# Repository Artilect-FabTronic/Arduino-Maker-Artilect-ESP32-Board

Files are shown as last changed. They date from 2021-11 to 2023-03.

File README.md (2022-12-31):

# Arduino-Maker-Artilect-ESP32-Board

Conception d'une carte électronique permettant d'accueillir le module **ESP32-WROOM-32D** pour les ateliers Arduino ESP32 :

<!--
![Arduino-Maker-Artilect](/Images/Arduino-Maker-Artilect-Web.png)
-->
<html>
<table align='left' border='0' cellpadding='0'>
<tr class="noBorder">
<td>
<div style="margin: 0 auto; text-align: center">
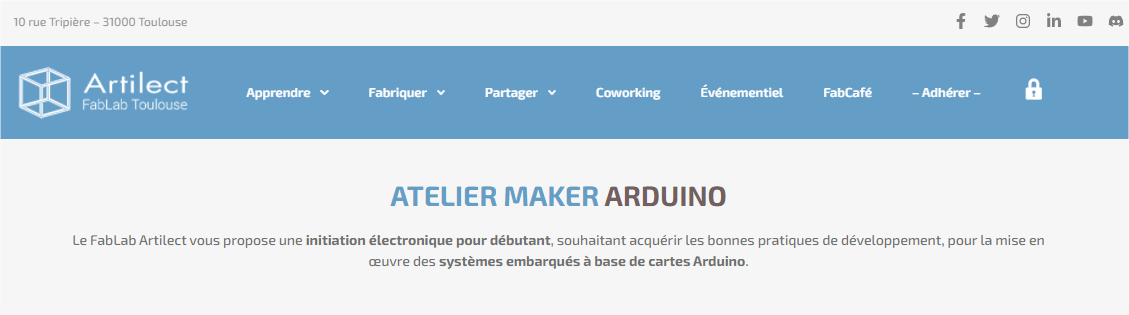
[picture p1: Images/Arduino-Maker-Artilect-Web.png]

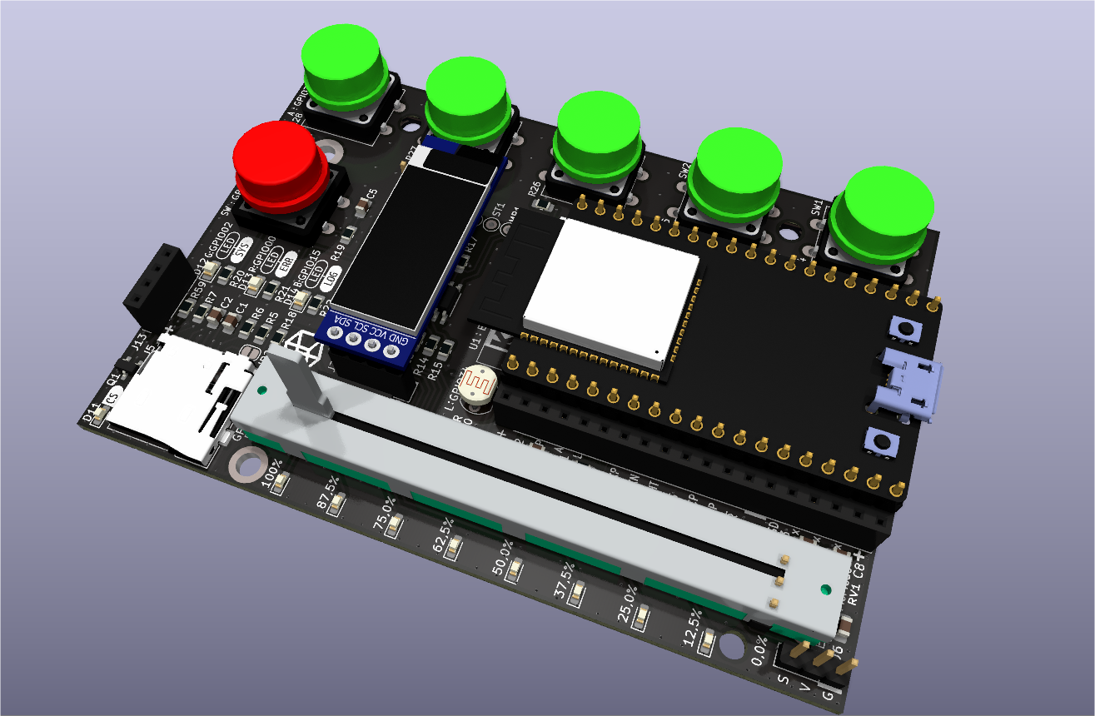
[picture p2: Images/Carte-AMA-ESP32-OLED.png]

</div>
</td>
</tr>
<tr class="noBorder">
<td>
<b>*** Objectifs ***</b><br />
Initiation à l'électronique pour débutant, souhaitant acquérir les bonnes pratiques de développement, pour la mise en œuvre des systèmes embarqués à base de cartes Arduino type ESP32 :<br /><br />
<ul>
  <li>Découvrir la programmation des cartes Arduino en langage C/C++ à travers des cas pratiques.</li>
  <li>Précautions de mise en œuvre, sécurité d’utilisation, alimentation de la carte et des périphériques.</li>
  <li>Prise en main des cartes microcontrôleurs ESP32.</li>
  <li>Mise en œuvre de nombreux périphériques d’entrée/sortie.</li>
  <li>Mise en oeuvre ESP32 avec PlatformIO.</li>
  <li>Vers les bases d’Arduino et au-delà...</li>
</ul>
</td>
</tr>
<tr class="noBorder">
<td>
<div style="margin: 0 auto; text-align: center">
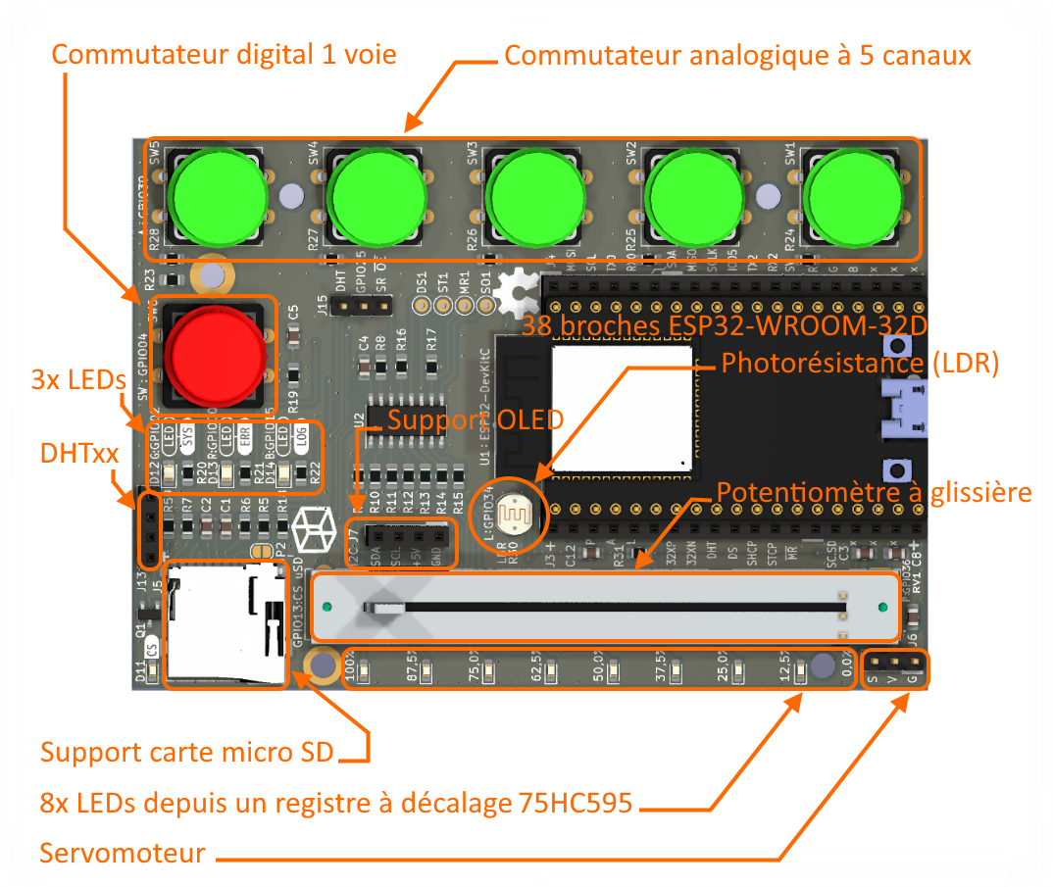
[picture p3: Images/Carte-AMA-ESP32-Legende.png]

</div>
</td>
</tr>
</table>
</p>
<hr>
<br />
</html>

[FabTronic](https://artilect.fr/fabtronic/), la section thématique des makers autour de l’électronique.

<html>
<p>
<table align='left' border='0' cellpadding='0'>
<tr class="noBorder">
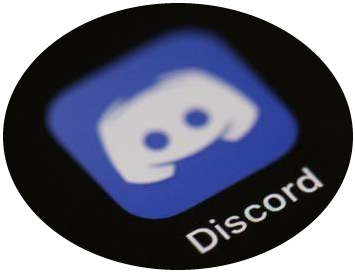
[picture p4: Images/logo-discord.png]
<td></td>
<td>Pour plus d'informations, venez nous rendre visite sur notre chaîne Discord à l'adresse : <a href="https://discord.gg/aPnZ5Q7w6Q">https://discord.gg/aPnZ5Q7w6Q</a><br />
Une fois connecté au serveur FabTronic, nous vous invitons à vous présenter dans le salon <b><i>#présentation</i></b>
</td>
</tr>
</table>
</p>
<hr>
<br />
</html>

---

## [Documentation](Docs/README.md)

### Logiciel utilisé pour la conception de la carte électronique

[KiCad EDA - Logiciel open source de capture schématique et de conception de circuits imprimés](https://kicad.org/)

Téléchargement [Windows All Stable Releases > kicad-6.0.10-x86_64.exe](https://downloads.kicad.org/kicad/windows/explore/stable)

[Logiciel open source](https://fr.wikipedia.org/wiki/Open_source) [EDA](https://fr.wikipedia.org/wiki/Conception_assist%C3%A9e_par_ordinateur_pour_l%27%C3%A9lectronique) / [CAO électronique](https://en.wikipedia.org/wiki/Comparison_of_EDA_software) pour Windows, macOS et Linux.

[Retrouvez la schématique de la carte, ainsi que la liste de matériels nécessaire pour l'assemblage (BOM).](Docs/README.md)

---

## Open Source Hardware Association

<!-- ![oshw-logo](oshw-logo-200-px.png) -->

<html>
<div style="margin: 0 auto; text-align: left">
<table align='left' border='0' cellpadding='0'>
<tr class="noBorder">
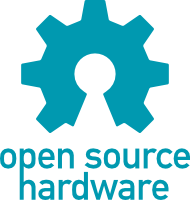
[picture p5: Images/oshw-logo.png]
<td align='center' border='0'></td>
<tr class="noBorder">
<td align='center' border='0'><a href="https://www.oshwa.org/" title="" target="_blank">Source : https://www.oshwa.org/</a></td>
</tr>
</table>
</div>
</html>

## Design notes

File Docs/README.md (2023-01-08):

# Documentation technique du projet

<html>
<div style="margin: 0 auto; text-align: center">
<table align='center' border='0' cellpadding='0'>
<tr class="noBorder">
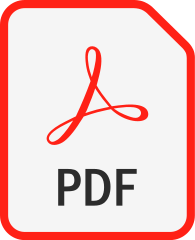
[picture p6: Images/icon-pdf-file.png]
<td></td>
<td><a href="CAO-KiCad-AMA-ESP32-Board.pdf" title="Document PDF de la schématique" target="_blank">Schématique de la carte "<I>A-M-A-ESP32-Board</I>"</a></td>
</tr>
</table>
</div>
</html>

---

## La carte A-M-A-ESP32-Board

| Placement des composants sur une face | Sérigraphie coté cuivre |
| :---: | :---: |
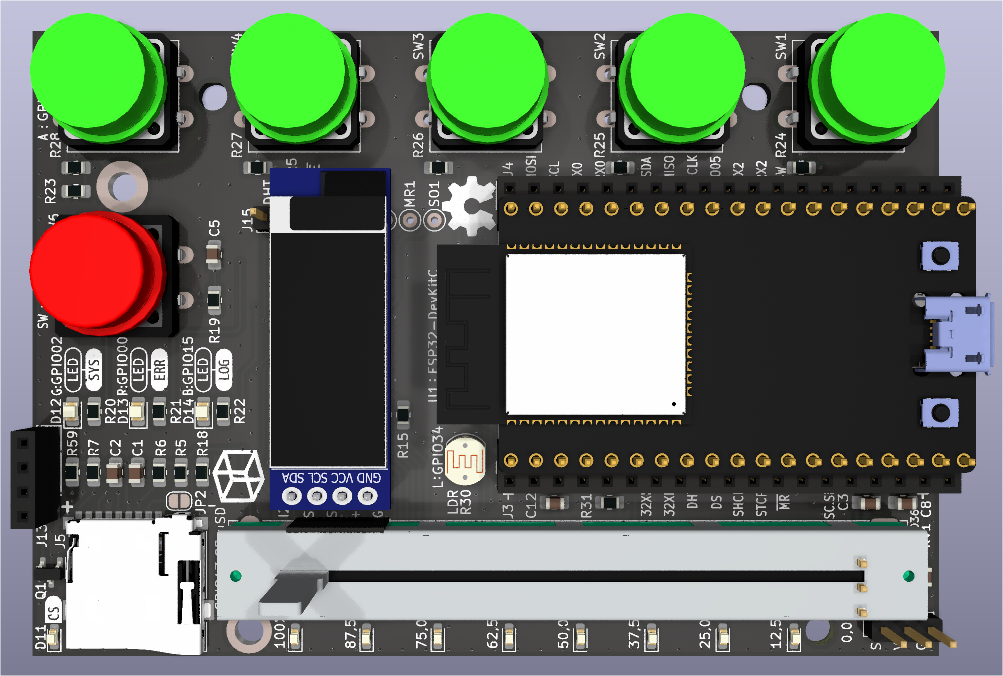
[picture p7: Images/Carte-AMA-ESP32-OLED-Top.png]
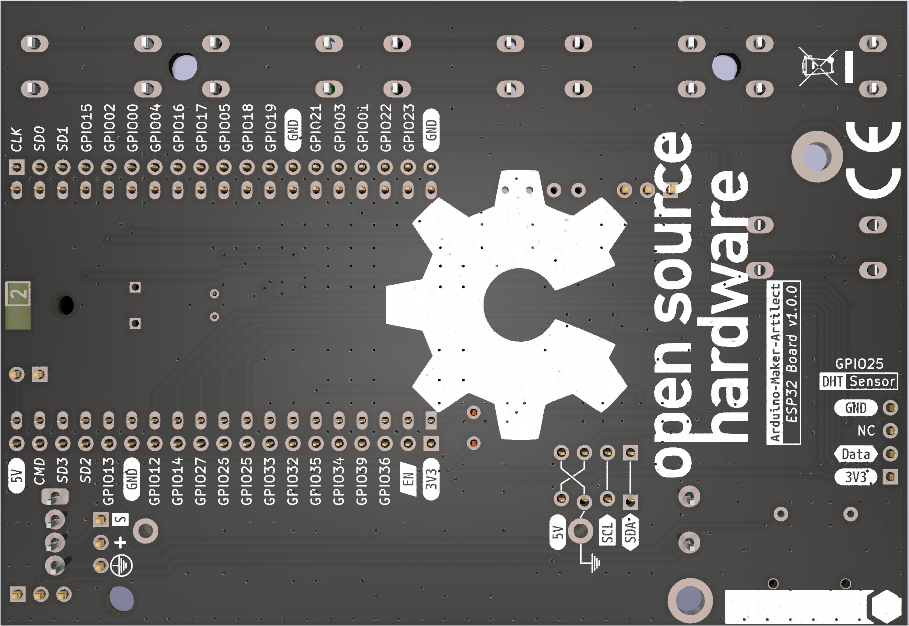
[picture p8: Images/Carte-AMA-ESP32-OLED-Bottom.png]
|  |  |
| Vue de dessus | Vue de dessous |

Voir la liste des composants et le coût de la carte : [Bill Of Materials (BOM)](BOM.md)

Datasheet [ESP32-DevKitC-1](https://docs.espressif.com/projects/arduino-esp32/en/latest/boards/ESP32-DevKitC-1.html)

<!--
<a href="https://fr.aliexpress.com/item/32864722159.html" title="ESP32-WROOM-32D, 38 pin" target="_blank"><img src="../Images/ESP32-WROOM-32D.png" width="480" border="0"></a>
-->

---

Montage de la carte :

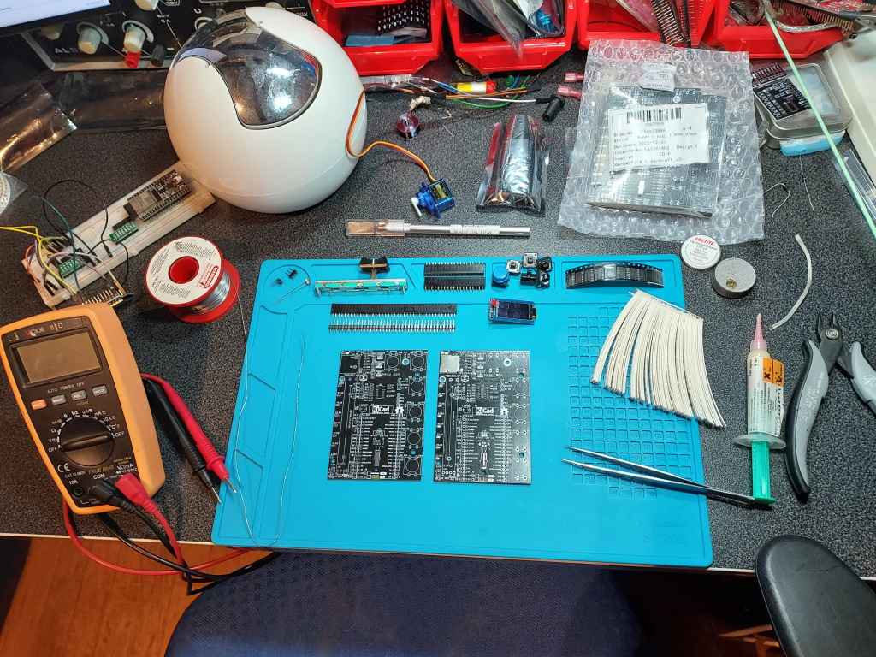
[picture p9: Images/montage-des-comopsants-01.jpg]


---

## Brochage de la carte ESP32-WROOM-32D, 38 broches

<!-- Voir aussi https://www.studiopieters.nl/esp32-pinout/ -->

<html>
<div style="margin: 0 auto; text-align: center">
<table align='center' border='0' cellpadding='0'>
<tr class="noBorder">
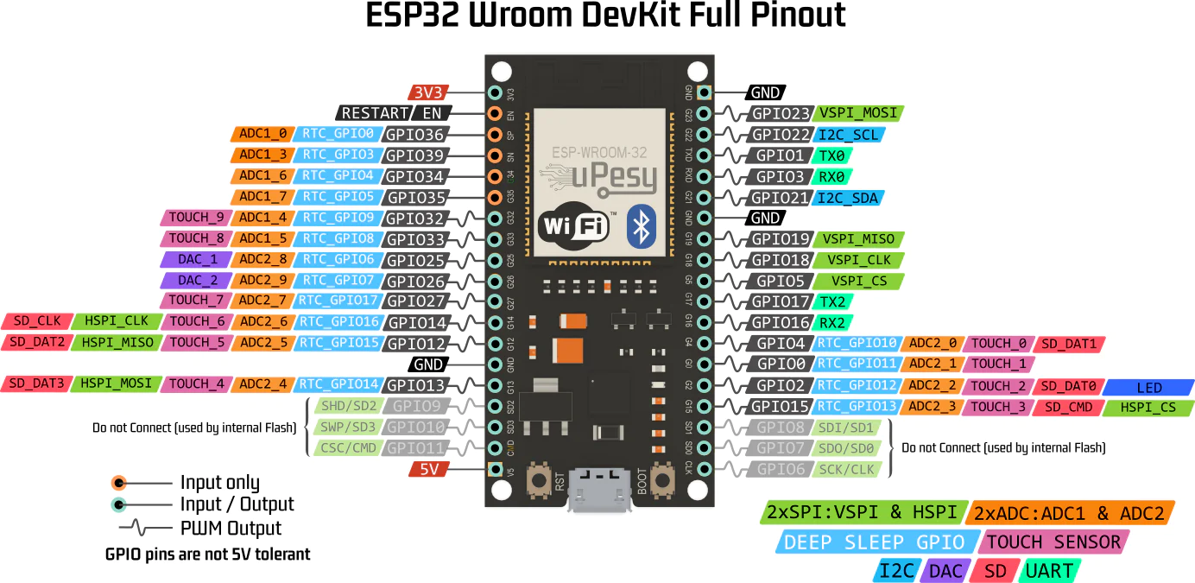
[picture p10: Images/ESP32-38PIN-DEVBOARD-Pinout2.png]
<td></td>
<tr class="noBorder">
<td><a href="https://cdn.shopify.com/s/files/1/0609/6011/2892/files/doc-esp32-pinout-reference-wroom-devkit.png" title="" target="_blank">Source : cdn.shopify.com image esp32-pinout</a></td>
</tr>
</table>
</div>
</html>

---

<html>
<div style="margin: 0 auto; text-align: center">
<table align='center' border='0' cellpadding='0'>
<tr class="noBorder">
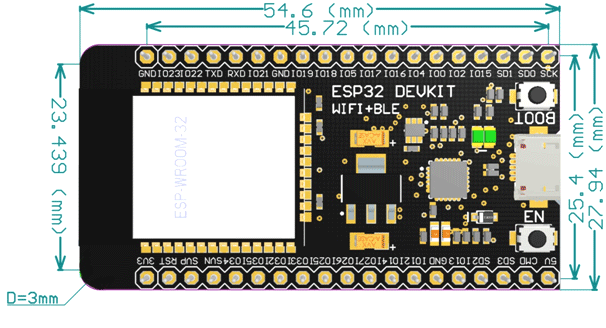
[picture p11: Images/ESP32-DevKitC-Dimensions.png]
<td></td>
<tr class="noBorder">
<td><a href="https://components101.com/microcontrollers/esp32-devkitc" title="" target="_blank">Source : components101.com image ESP32 2D Model</a></td>
</tr>
</table>
</div>
</html>

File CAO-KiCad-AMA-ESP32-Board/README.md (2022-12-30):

# Réalisation du PCB

## Board Stackup > Design Rules

### Grosses pistes

Net Class = Default
Clearance = 0.34 mm
Track Width = 1 mm
Via Size = 1 mm
Via Hole = 0.4 mm

### https://jlcpcb.com/capabilities/pcb-capabilities

Net Class = Default
Clearance = 0.14 mm
Track Width = 0.14 mm
Via Size = 0.5 mm
Via Hole = 0.3 mm

## INTRODUCTION TO THE ESP32 GUIDE SERIES

[Digital Output Experiment Using An LED](https://techexplorations.com/guides/esp32/begin/digitalout/)

BEGINNER’S GUIDE TO THE 595 SHIFT REGISTER
https://www.idogendel.com/en/archives/211

Cours Systèmes Embarqués: BUS I2C
https://www.technologuepro.com/cours-systemes-embarques/cours-systemes-embarques-Bus-I2C.htm
http://electro8051.free.fr/I2C/busi2c.htm

## JLCPCB

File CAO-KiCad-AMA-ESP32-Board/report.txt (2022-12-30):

Warning: Footprint 'REF**' has no assigned symbol.
Warning: Footprint 'Layer-x2' has no assigned symbol.
Warning: Footprint 'REF**' has no assigned symbol.
Warning: Footprint 'REF**' has no assigned symbol.
Warning: Footprint 'REF**' has no assigned symbol.
Warning: Footprint 'R45' is not present on PCB. Corresponding symbols in schematic must be manually deleted (if desired).
Warning: Footprint 'D25' is not present on PCB. Corresponding symbols in schematic must be manually deleted (if desired).
Warning: Footprint 'U3' is not present on PCB. Corresponding symbols in schematic must be manually deleted (if desired).
Warning: Footprint 'R41' is not present on PCB. Corresponding symbols in schematic must be manually deleted (if desired).
Warning: Footprint 'J12' is not present on PCB. Corresponding symbols in schematic must be manually deleted (if desired).
Warning: Footprint 'R36' is not present on PCB. Corresponding symbols in schematic must be manually deleted (if desired).
Warning: Footprint 'D16' is not present on PCB. Corresponding symbols in schematic must be manually deleted (if desired).
Warning: Footprint 'R39' is not present on PCB. Corresponding symbols in schematic must be manually deleted (if desired).
Warning: Footprint 'R35' is not present on PCB. Corresponding symbols in schematic must be manually deleted (if desired).
Warning: Footprint 'R3' is not present on PCB. Corresponding symbols in schematic must be manually deleted (if desired).
Warning: Footprint 'Q2' is not present on PCB. Corresponding symbols in schematic must be manually deleted (if desired).
Warning: Footprint 'D2' is not present on PCB. Corresponding symbols in schematic must be manually deleted (if desired).
Warning: Footprint 'D20' is not present on PCB. Corresponding symbols in schematic must be manually deleted (if desired).
Warning: Footprint 'J11' is not present on PCB. Corresponding symbols in schematic must be manually deleted (if desired).
Warning: Footprint 'R50' is not present on PCB. Corresponding symbols in schematic must be manually deleted (if desired).
Warning: Footprint 'JP1' is not present on PCB. Corresponding symbols in schematic must be manually deleted (if desired).
Warning: Footprint 'R48' is not present on PCB. Corresponding symbols in schematic must be manually deleted (if desired).
Warning: Footprint 'D23' is not present on PCB. Corresponding symbols in schematic must be manually deleted (if desired).
Warning: Footprint 'R38' is not present on PCB. Corresponding symbols in schematic must be manually deleted (if desired).
Warning: Footprint 'C9' is not present on PCB. Corresponding symbols in schematic must be manually deleted (if desired).
Warning: Footprint 'R32' is not present on PCB. Corresponding symbols in schematic must be manually deleted (if desired).
Warning: Footprint 'D24' is not present on PCB. Corresponding symbols in schematic must be manually deleted (if desired).
Warning: Footprint 'R57' is not present on PCB. Corresponding symbols in schematic must be manually deleted (if desired).
Warning: Footprint 'MR2' is not present on PCB. Corresponding symbols in schematic must be manually deleted (if desired).
Warning: Footprint 'ST2' is not present on PCB. Corresponding symbols in schematic must be manually deleted (if desired).
Warning: Footprint 'OE2' is not present on PCB. Corresponding symbols in schematic must be manually deleted (if desired).
Warning: Footprint 'BZ1' is not present on PCB. Corresponding symbols in schematic must be manually deleted (if desired).
Warning: Footprint 'J10' is not present on PCB. Corresponding symbols in schematic must be manually deleted (if desired).
Warning: Footprint 'R55' is not present on PCB. Corresponding symbols in schematic must be manually deleted (if desired).
Warning: Footprint 'R44' is not present on PCB. Corresponding symbols in schematic must be manually deleted (if desired).
Warning: Footprint 'R46' is not present on PCB. Corresponding symbols in schematic must be manually deleted (if desired).
Warning: Footprint 'J18' is not present on PCB. Corresponding symbols in schematic must be manually deleted (if desired).
Warning: Footprint 'D29' is not present on PCB. Corresponding symbols in schematic must be manually deleted (if desired).
Warning: Footprint 'R34' is not present on PCB. Corresponding symbols in schematic must be manually deleted (if desired).
Warning: Footprint 'R42' is not present on PCB. Corresponding symbols in schematic must be manually deleted (if desired).
Warning: Footprint 'D18' is not present on PCB. Corresponding symbols in schematic must be manually deleted (if desired).
Warning: Footprint 'DS2' is not present on PCB. Corresponding symbols in schematic must be manually deleted (if desired).
Warning: Footprint 'J9' is not present on PCB. Corresponding symbols in schematic must be manually deleted (if desired).
Warning: Footprint 'D26' is not present on PCB. Corresponding symbols in schematic must be manually deleted (if desired).
Warning: Footprint 'R33' is not present on PCB. Corresponding symbols in schematic must be manually deleted (if desired).
Warning: Footprint 'D19' is not present on PCB. Corresponding symbols in schematic must be manually deleted (if desired).
Warning: Footprint 'M1' is not present on PCB. Corresponding symbols in schematic must be manually deleted (if desired).
Warning: Footprint 'C10' is not present on PCB. Corresponding symbols in schematic must be manually deleted (if desired).
Warning: Footprint 'R54' is not present on PCB. Corresponding symbols in schematic must be manually deleted (if desired).
Warning: Footprint 'R53' is not present on PCB. Corresponding symbols in schematic must be manually deleted (if desired).
Warning: Footprint 'R51' is not present on PCB. Corresponding symbols in schematic must be manually deleted (if desired).
Warning: Footprint 'R1' is not present on PCB. Corresponding symbols in schematic must be manually deleted (if desired).
Warning: Footprint 'R58' is not present on PCB. Corresponding symbols in schematic must be manually deleted (if desired).
Warning: Footprint 'J2' is not present on PCB. Corresponding symbols in schematic must be manually deleted (if desired).
Warning: Footprint 'R37' is not present on PCB. Corresponding symbols in schematic must be manually deleted (if desired).
Warning: Footprint 'D1' is not present on PCB. Corresponding symbols in schematic must be manually deleted (if desired).
Warning: Footprint 'R47' is not present on PCB. Corresponding symbols in schematic must be manually deleted (if desired).
Warning: Footprint 'R52' is not present on PCB. Corresponding symbols in schematic must be manually deleted (if desired).
Warning: Footprint 'D30' is not present on PCB. Corresponding symbols in schematic must be manually deleted (if desired).
Warning: Footprint 'D28' is not present on PCB. Corresponding symbols in schematic must be manually deleted (if desired).
Warning: Footprint 'R40' is not present on PCB. Corresponding symbols in schematic must be manually deleted (if desired).
Warning: Footprint 'D27' is not present on PCB. Corresponding symbols in schematic must be manually deleted (if desired).
Warning: Footprint 'R43' is not present on PCB. Corresponding symbols in schematic must be manually deleted (if desired).
Warning: Footprint 'R56' is not present on PCB. Corresponding symbols in schematic must be manually deleted (if desired).
Warning: Footprint 'C11' is not present on PCB. Corresponding symbols in schematic must be manually deleted (if desired).
Warning: Footprint 'R2' is not present on PCB. Corresponding symbols in schematic must be manually deleted (if desired).
Warning: Footprint 'D22' is not present on PCB. Corresponding symbols in schematic must be manually deleted (if desired).
Warning: Footprint 'SW7' is not present on PCB. Corresponding symbols in schematic must be manually deleted (if desired).
Warning: Footprint 'D21' is not present on PCB. Corresponding symbols in schematic must be manually deleted (if desired).
Warning: Footprint 'J1' is not present on PCB. Corresponding symbols in schematic must be manually deleted (if desired).
Warning: Footprint 'D17' is not present on PCB. Corresponding symbols in schematic must be manually deleted (if desired).
Warning: Footprint 'R4' is not present on PCB. Corresponding symbols in schematic must be manually deleted (if desired).
Warning: Footprint 'R49' is not present on PCB. Corresponding symbols in schematic must be manually deleted (if desired).
Warning: Footprint 'D15' is not present on PCB. Corresponding symbols in schematic must be manually deleted (if desired).

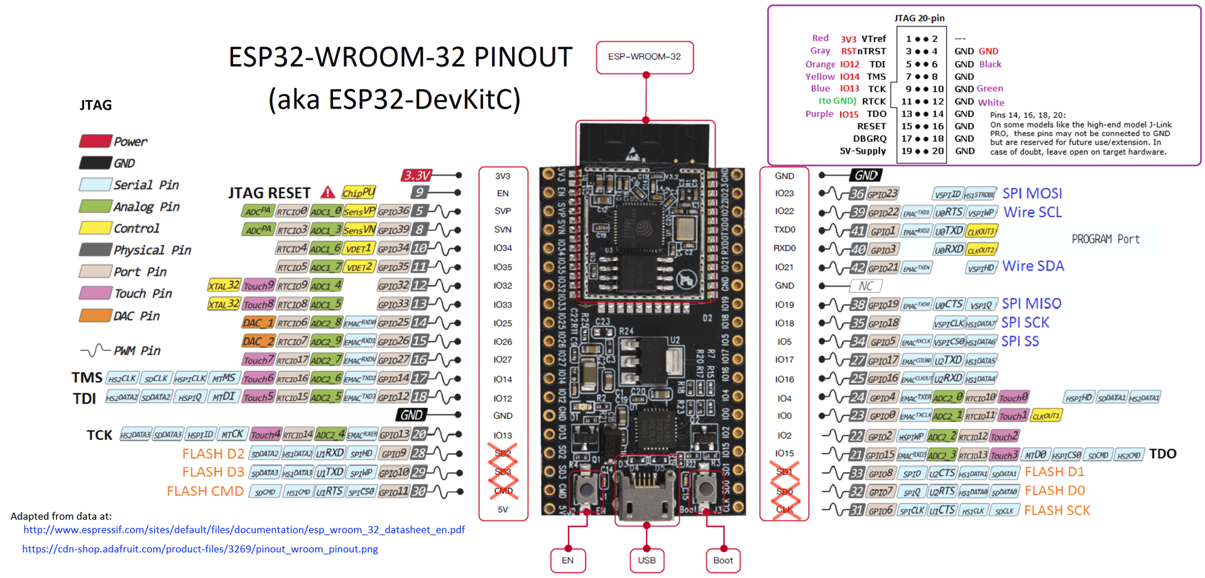
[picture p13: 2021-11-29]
Images/ESP32-38PIN-DEVBOARD-Pinout.png

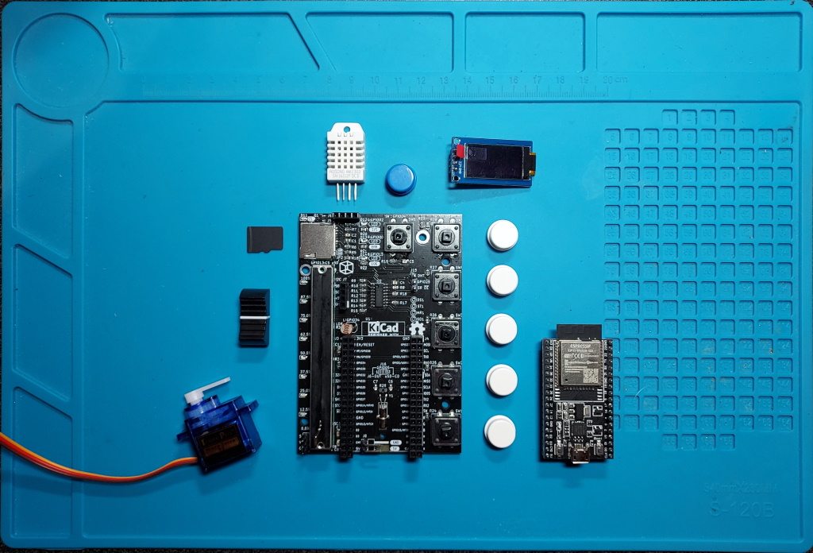
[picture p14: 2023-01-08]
Images/carte-et-accessoires.jpg

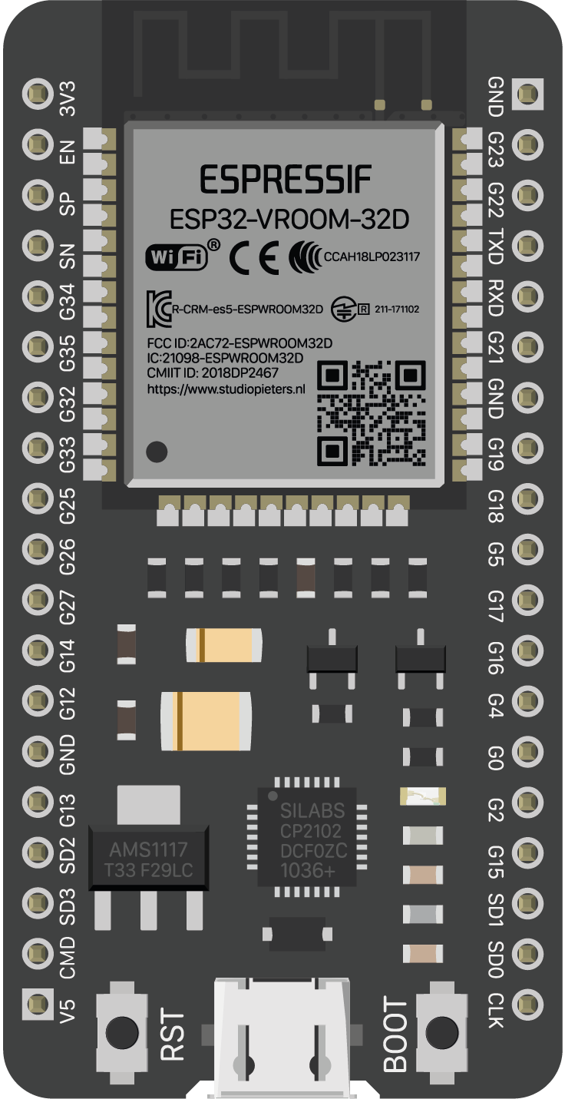
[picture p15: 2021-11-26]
Images/ESP32-WROOM-32D-38pin.png

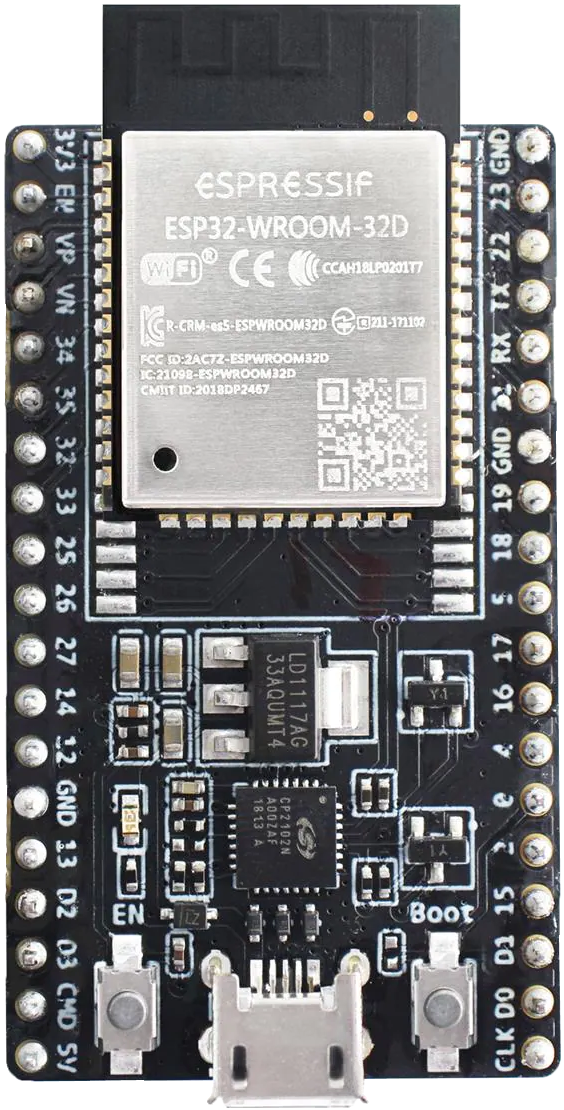
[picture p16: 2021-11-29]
Images/ESP32-DevKitC-32D.png

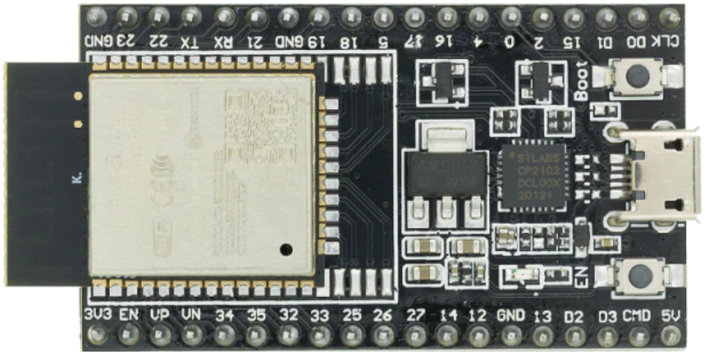
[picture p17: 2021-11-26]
Images/ESP32-WROOM-32D.png

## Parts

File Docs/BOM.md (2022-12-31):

# Liste des composants pour la carte A-M-A-ESP32-Board

Les tarifs présenté ici, à la date décembre 2022, tiennent compte des frais de port et de la TVA et sont données à titre indicatif, car ils sont susceptibles d'évoluer dans le temps.

| Référence | Description | Distributeur | Référence fabricant | Quantité | Par multiple de | Prix unitaire<br />avec frais de port | Total des lignes |
| :--- | :--- | :--- | :--- | :---: | --- | ---: | ---: |
| PCB | Carte électronique, A-M-A-ESP32-Board | JLCPCB | / | 1 | 10 unités | 20,86 € | 2,086 € |
| U1 | Carte de développement ESP32-WROOM-32D | AliExpress | [SAMIORE Store][URL_ESP32] | 1 | l'unité | 5,25 € | 5,25 € |
| de R6 à R31 | 60 valeurs 1% SMD 0805 Résistances Kit 0 R - 10M Ohms | AliExpress | [CHANZON Official Store][URL_LOT_R0805] | 1 | l'unité | 5,44 € | 5,44 € |
| RV1 | Résistance de potentiomètre B103 10K, potentiomètre coulissant Double linéaire  | AliExpress | [diymore Alice1101983 Store][URL_SLIDER_10K] | 1 | l'unité | 1,95 € | 1,95 € |
| R30 | Résistance photoélectrique photosensible LDR | AliExpress | [Victory Electronic][URL_LDR_5528] | 1 | 20 unités | 1,75 € | 0,0875 € |
| C1, C12 | Condensateur au tantale de Type C, Capacité: C 16V10UF | AliExpress | [IBUW Electron Component Store][URL_CP_10U]  | 2 | 10 unités | 2,25 € | 0,45 € |
| C2, C3, C4, C5, C8, C13 | condensateur céramique multicouche, 100n 0805 SMD | AliExpress | [DSSRQI Official Store][URL_C] | 6 | 100 unités | 2,26 € | 0,1356 € |
| Q1 | MOSFET P, IRLML6402 | AliExpress | [SUQ Official Store][URL_IRLML6402] | 1 | 100 unités | 7,00 € | 0,07 € |
| U2 | Shift Register, Couleur: 50PCS-74HC595D | AliExpress | [Computer chip Store][URL_74HC595] | 1 | 50 unités | 4,39 € | 0,0878 € |
| D3, D4, D5, D6, D7, D8, D9, D10, D11<br />D12, D13, D14 | SMD 0603/0805 LED | AliExpress | [DSSRQI Official Store][URL_LED] | 12 | 5x100 unités | 4,17 € | 0,10 € |
| SW1, SW2, SW3, SW4, SW5, SW6 | Ensemble de 100 boutons poussoirs tactiles momentanés, 12x12x7.3MM | AliExpress | [HESAI 3C Tool Store][URL_SWITCH] | 6 | 100 unités | 4,97 € | 0,30 € |
| J3, J4 | Connecteur femelle à Double rangée 2x19Pin, 2.54mm, | AliExpress | [TLZWLA Official Store][URL_CONN254_2X19P] | 2 | 10 unités | 3,16 € | 0,632 € |
| J6, J7, J8, J13, J15, J17 | Barettes male/femelle 2.54mm, broches sécables | AliExpress | [EziUsin Official Store][URL_CONN254] | 5 | 20 unités | 2,86 € | 0,715 € |
| J5 | Adaptateur de prise de carte Micro SD TF, Type TransFlash Push-Push | AliExpress | [Stationery world Store][URL_SOCKET_MSD] | 1 | 10 unités | 1,91 € | 0,191 € |
| __________________________________ | _______________________________________________________________________________ | ________________ | _____________________________ | ________ | _________________ | _________________ | ___________ |
| | | | | | | TOTAL | 17,50 € |

## Composants accessoires complémentaire à la carte A-M-A-ESP32-Board

| Référence | Description | Distributeur | Référence fabricant | Quantité | Par multiple de | Prix unitaire | Total des lignes |
| :--- | :--- | :--- | :--- | :---: | --- | ---: | ---: |
| Y1 | Oscillateur à cristal 32.768KHZ, cylindre 3x8mm | AliExpress | [YDF IC Store][URL_Q32768HZ] | 1 | 10 unités | 1,91 € | 0,191 € |
| C6, C7 | Condensateur céramique multicouche, 10n 0805 SMD | AliExpress | [DSSRQI Official Store][URL_C] | 2 | 100 unités | 2,26 € | 0,0452 € |
| R29 | Résistance 10M 0805 SMD | AliExpress | [CHANZON Official Store][URL_LOT_R0805] | 1 | l'unité | 0,10 € | 0,10 € |
| sur J6 | Servomoteur, SG90 9g Mini Micro Servo | AliExpress | [U-Angel-1988 Official Store][URL_SERVO] | 1 | l'unité | 3,90 € | 3,90 € |
| sur J7 | Module OLED I2C 0.91 pouces, blanc/bleu 128X32 | AliExpress | [TENSTAR ROBOT GREAT WALL Store][URL_OLED]  | 1 | l'unité | 2,26 € | 2,26 € |
| sur J13 | DHT22 Sensor | AliExpress | [TZT teng Official Store][URL_DHT] | 1 | l'unité | 4,15 € | 4,15 € |
| sur J17 | MPU-6050 MPU6050 GY-521 accéléromètre capteur gyroscopique 6DOF trois axes IMU  | AliExpress | [e_goto Processors Store][URL_MPU6050] | 1 | l'unité | 3,47 € | 3,47 € |
| sur J5 | Micro SD Card (8GB de Mémoire Flash) | AliExpress | [Micro Memory Electronic Store][URL_MSD8GO] | 1 | l'unité | 3,46 € | 3,46 € |
| _________ | _______________________________________________________________________________ | ________________ | ____________________________ | ________ | _________________ | __________ | _________ |
| | | | | | | TOTAL | 17,60 € |

## Temps passé par Arnauld

| Description | Nombre d'heures |
| :--- | ---: |
| Définition du besoin et du cahier des charges | 1 h |
| Saisie de la schématique | 6 h |
| Création de symboles | 1 h |
| Revue de schémas | 1 h |
| Création d'empreintes | 2 h |
| Placement des composants | 3 h |
| Routage | 5 h |
| Placement des vias | 1 h |
| Revue du routage | 1 h |
| Documentation et mise en ligne sur GitHub | 4 h |
| Commande des composants | 2 h |
| Montage de la carte électronique | 2 h |
| Tests | 1 h |
| ____________________________________________  | _____________ |
| Total étude, conception, assemblage et tests  | 30 h |

<!-- Références des liens dans ce fichier BOM.md -->

[URL_ESP32]: https://fr.aliexpress.com/item/32864722159.html
[URL_CP_10U]: https://fr.aliexpress.com/item/1005001510640858.html
[URL_LOT_R0805]: https://fr.aliexpress.com/item/1005002364309989.html
[URL_SLIDER_10K]: https://fr.aliexpress.com/item/33045700105.html
[URL_LDR_5528]: https://fr.aliexpress.com/item/32976469984.html
[URL_IRLML6402]: https://fr.aliexpress.com/item/32716087801.html
[URL_74HC595]: https://fr.aliexpress.com/item/1005002274578264.html
[URL_C]: https://fr.aliexpress.com/item/32964553793.html
[URL_Q32768HZ]: https://fr.aliexpress.com/item/1005003752206302.html
[URL_LED]: https://fr.aliexpress.com/item/4000927747306.html
[URL_SWITCH]: https://fr.aliexpress.com/item/4001361256214.html
[URL_CONN254]: https://fr.aliexpress.com/item/32724478308.html
[URL_CONN254_2X19P]: https://fr.aliexpress.com/item/1005003335405213.html
[URL_SOCKET_MSD]: https://fr.aliexpress.com/item/4000324909050.html

[URL_MPU6050]: https://fr.aliexpress.com/item/33009159455.html
[URL_SERVO]: https://fr.aliexpress.com/item/32898059654.html
[URL_MSD8GO]: https://fr.aliexpress.com/item/1005004495732671.html
[URL_OLED]: https://fr.aliexpress.com/item/32798439084.html
[URL_DHT]: https://fr.aliexpress.com/item/32675222015.html

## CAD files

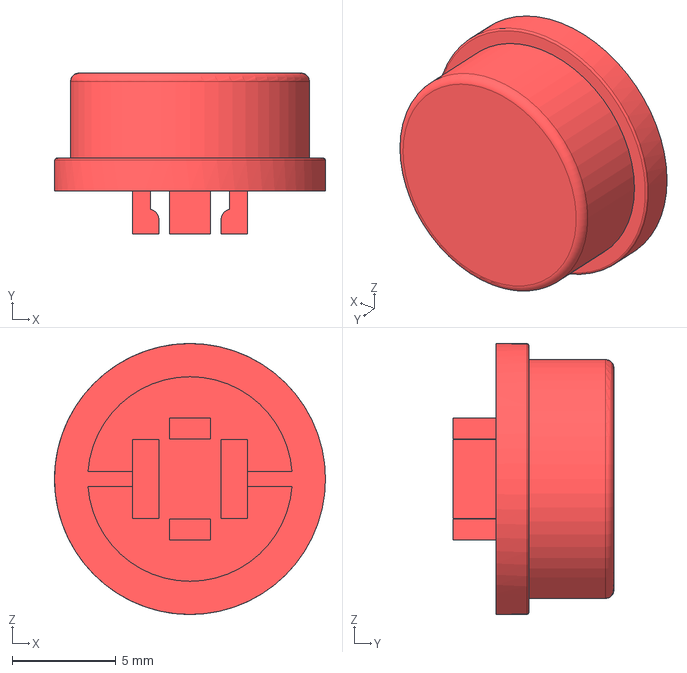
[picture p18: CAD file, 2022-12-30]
CAO-KiCad-AMA-ESP32-Board/local-packages3d/Push-Button-Cap-Red.step
13.1 x 7.75 x 13.1 mm

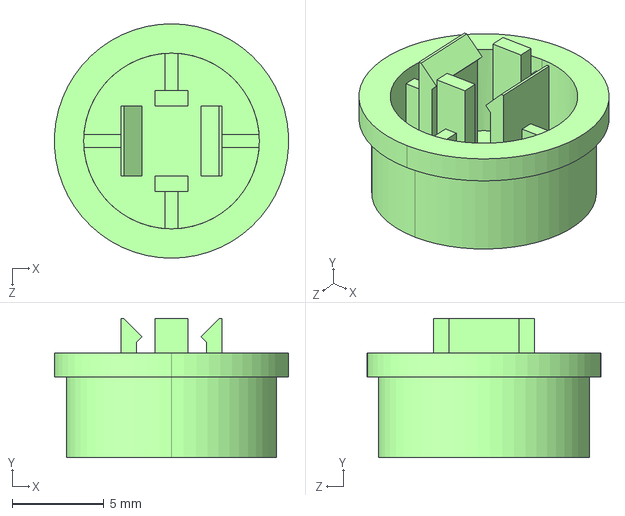
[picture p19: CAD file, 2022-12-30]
CAO-KiCad-AMA-ESP32-Board/local-packages3d/Tactile-Button-Cap-B3F-4055-12x12x7.3mm.STEP
12.8 x 7.60 x 12.8 mm

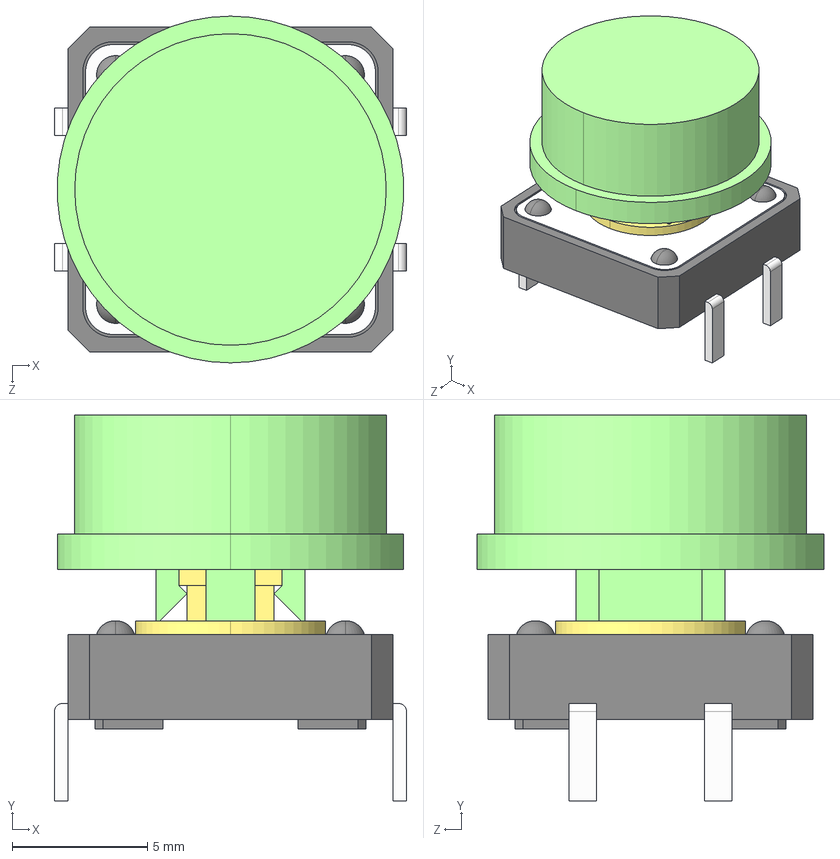
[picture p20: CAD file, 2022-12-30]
CAO-KiCad-AMA-ESP32-Board/local-packages3d/Push Button B3F-4055 with Cap.STEP
13.0 x 14.3 x 12.8 mm
Кнопка12х12х7,3
Tactile Button Caps for B3F-4055 12X12X7.3MM

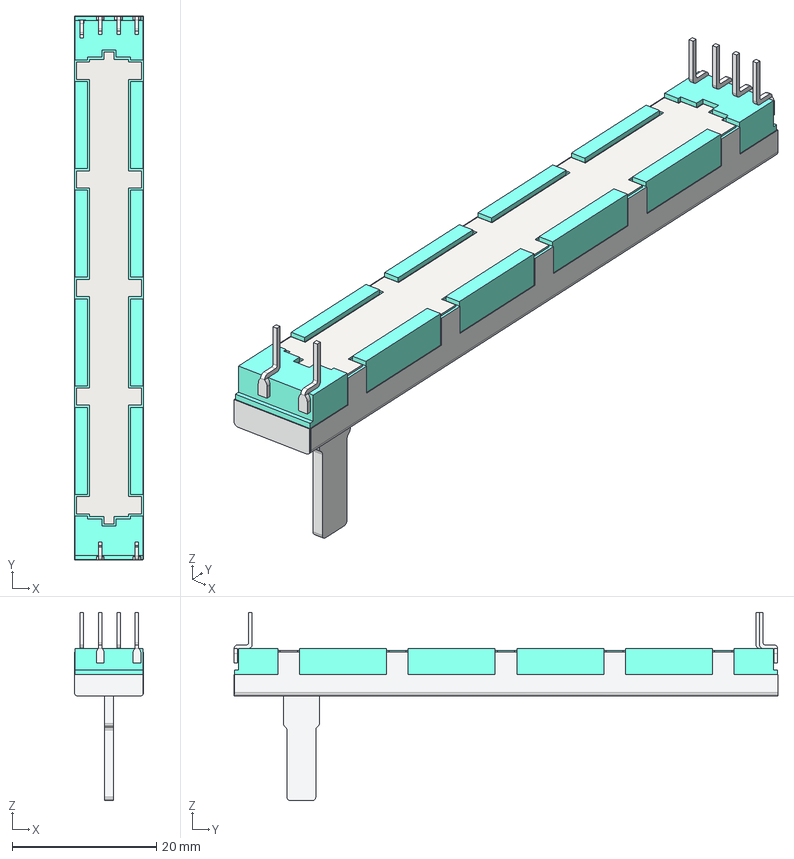
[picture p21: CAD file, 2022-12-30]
CAO-KiCad-AMA-ESP32-Board/local-packages3d/Potentiometer_75mm_Horizontal.step
9.60 x 75.4 x 26.1 mm
Slide Por - Slider
Slide Pot - Pins x 6

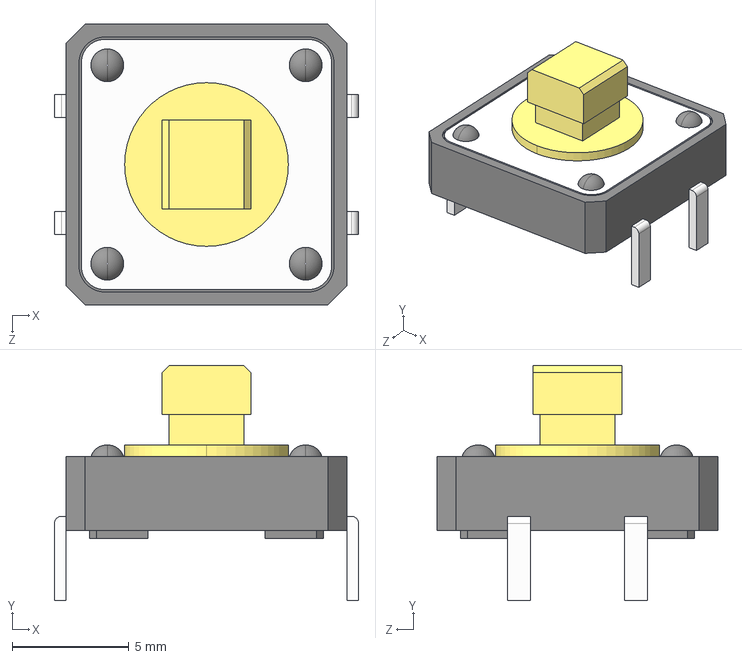
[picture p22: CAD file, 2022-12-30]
CAO-KiCad-AMA-ESP32-Board/local-packages3d/Tactile-Push-Button-B3F-405-12x12x7.3mm.STEP
13.0 x 10.1 x 12.0 mm

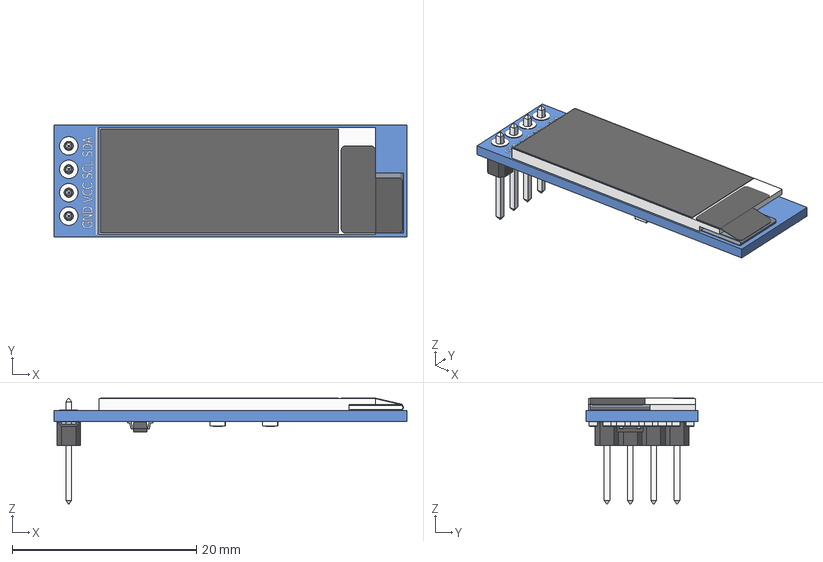
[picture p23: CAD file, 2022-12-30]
CAO-KiCad-AMA-ESP32-Board/local-packages3d/OLED_0.91_128x32.stp
38.3 x 12.1 x 11.5 mm
OLED_0.91_128x32
Pin Header 4 x 1 TH 2.54mm Pitch
RESC-0603 x 13
2SD0601A

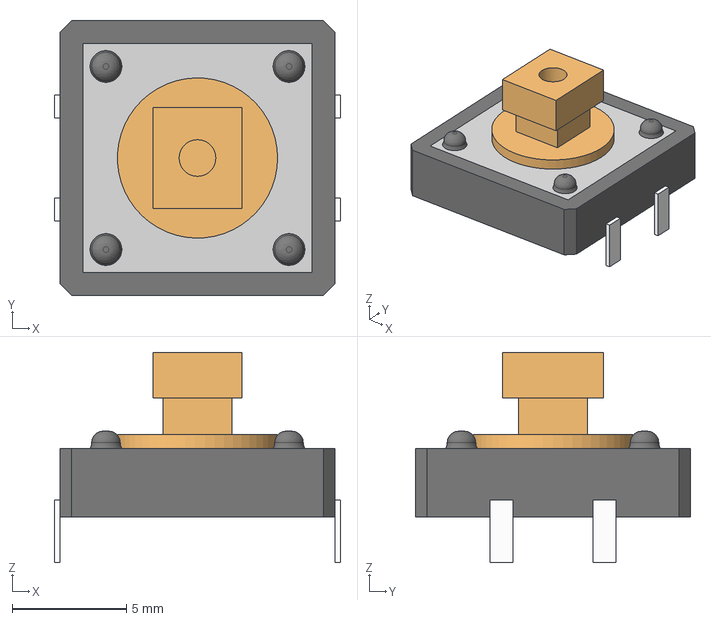
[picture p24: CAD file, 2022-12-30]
CAO-KiCad-AMA-ESP32-Board/local-packages3d/Switch-Push-Button.step
12.5 x 12.0 x 9.20 mm

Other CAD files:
CAO-KiCad-AMA-ESP32-Board/local-packages3d/Push-Button-Cap-Yellow.step
CAO-KiCad-AMA-ESP32-Board/local-packages3d/Push-Button-Cap-Green.step
CAO-KiCad-AMA-ESP32-Board/local-packages3d/Push-Button-Cap-Blue.step
CAO-KiCad-AMA-ESP32-Board/local-packages3d/Push-Button-Cap-White.step

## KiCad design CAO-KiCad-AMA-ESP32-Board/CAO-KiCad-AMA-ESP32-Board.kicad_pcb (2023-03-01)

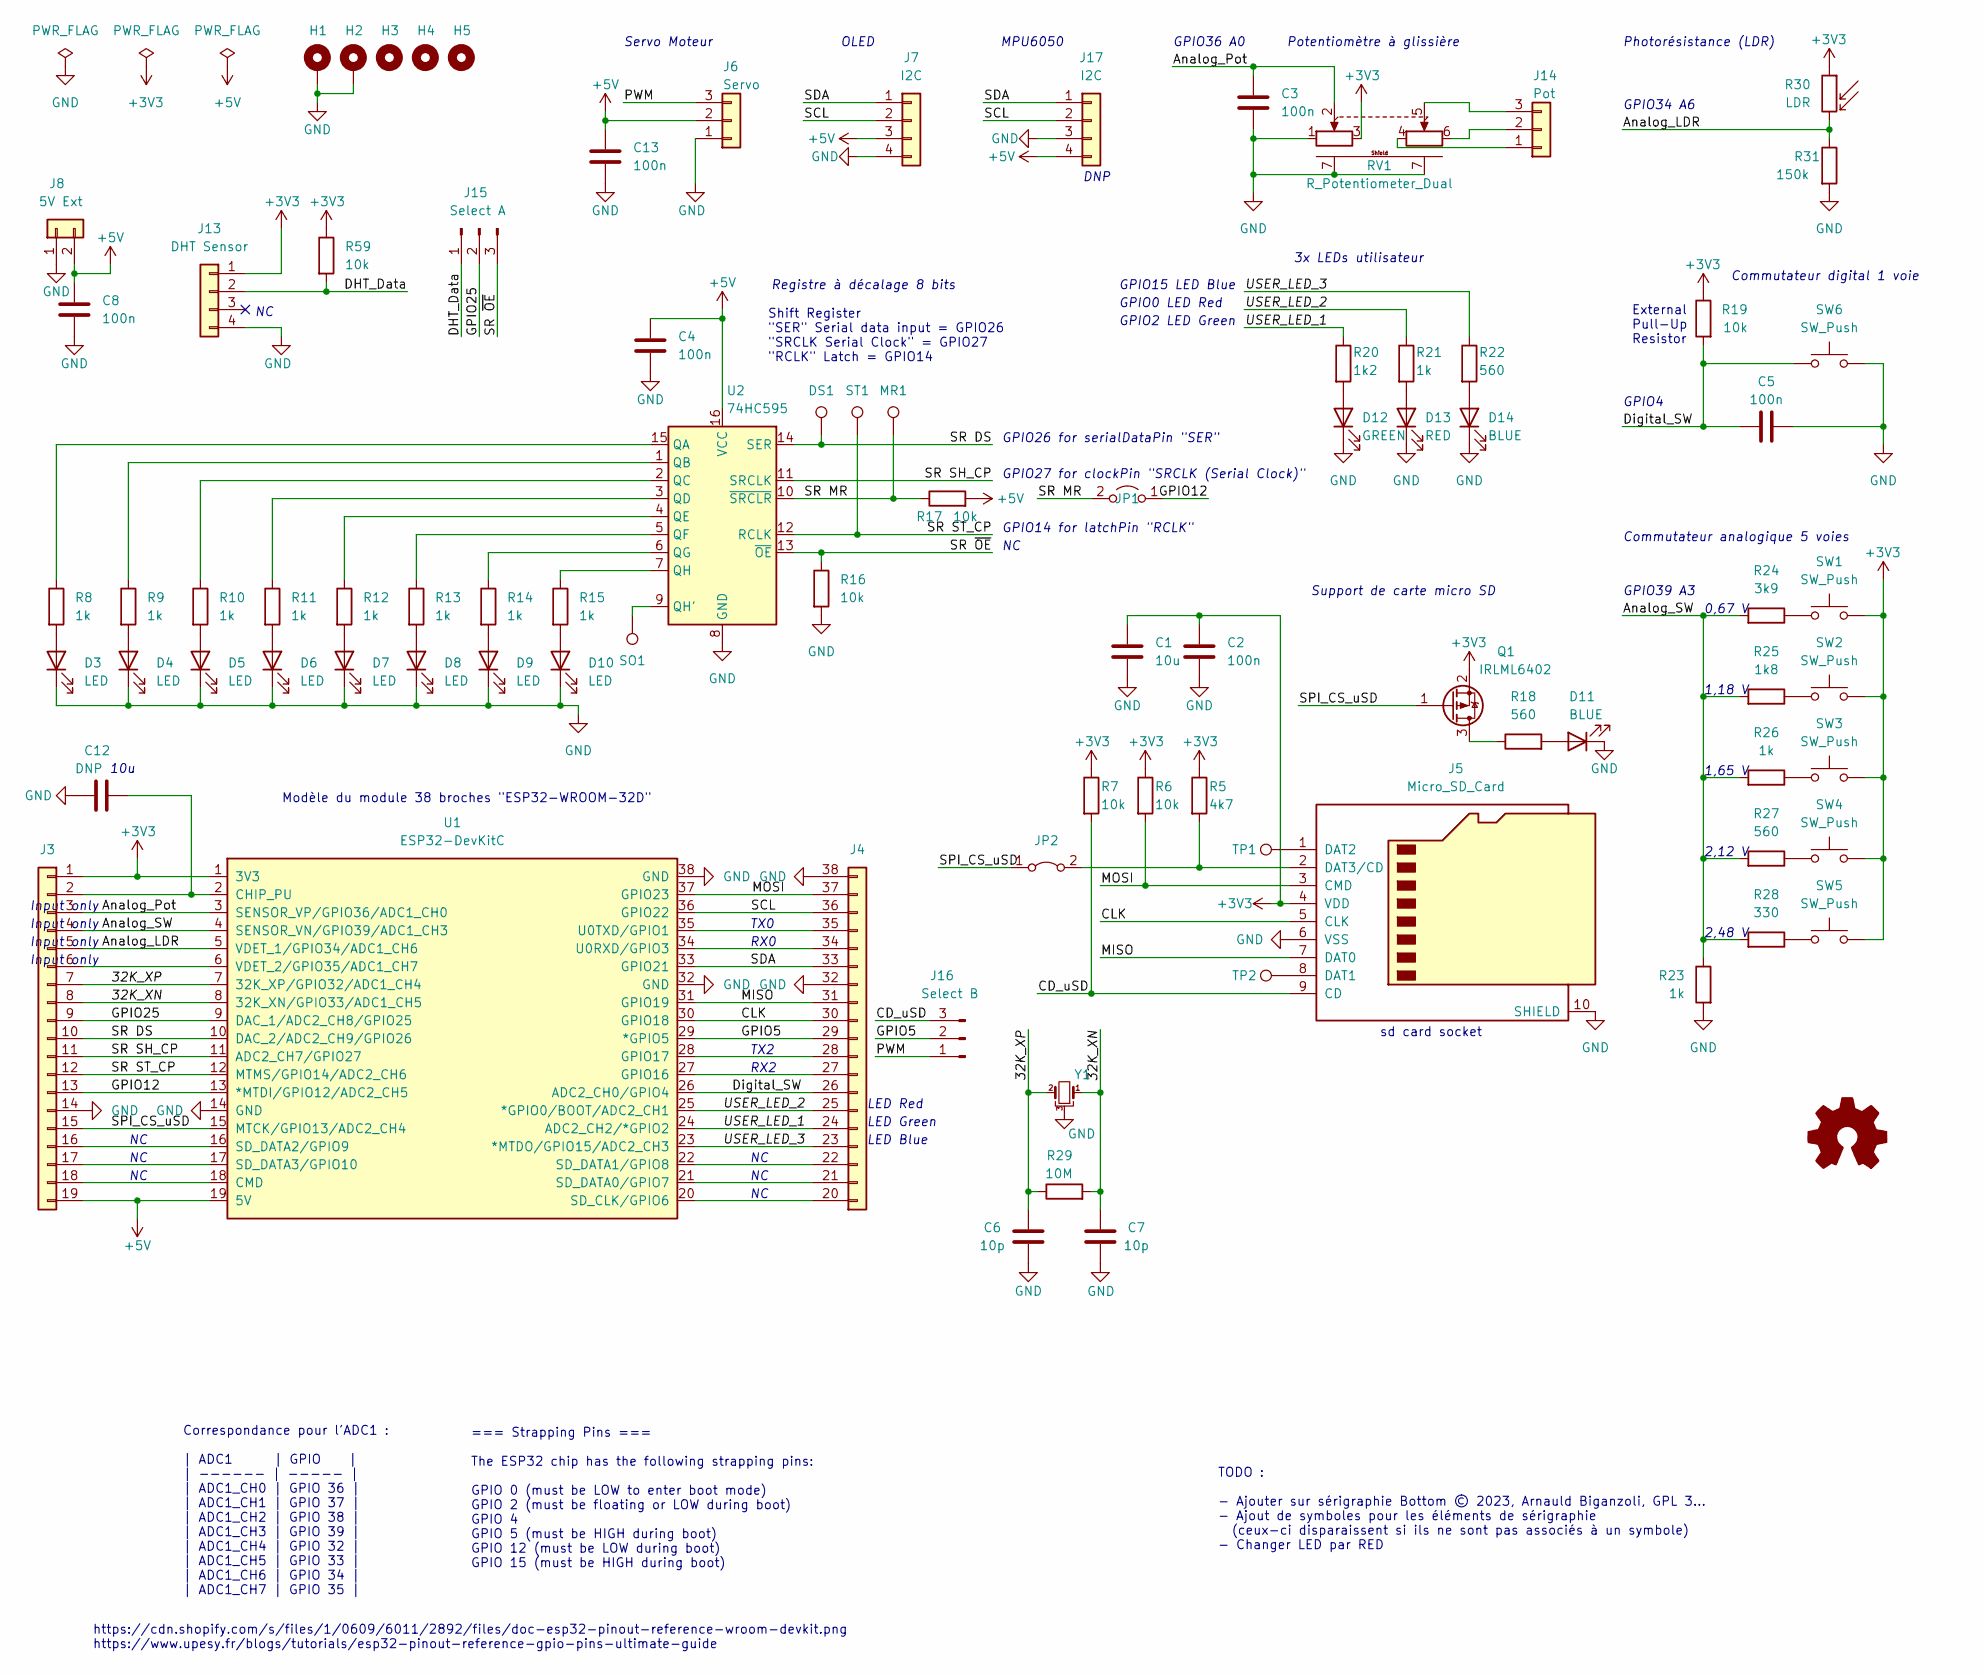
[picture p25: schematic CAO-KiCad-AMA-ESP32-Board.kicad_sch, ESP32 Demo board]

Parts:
C1: 10u; C_0805_2012Metric_Pad1.18x1.45mm_HandSolder
C2, C3, C4, C5, C8, C13: 100n; C_0805_2012Metric_Pad1.18x1.45mm_HandSolder
C6, C7: 10p; C_0805_2012Metric_Pad1.18x1.45mm_HandSolder
C12: DNP; C_0805_2012Metric_Pad1.18x1.45mm_HandSolder
D3, D4, D5, D6, D7, D8, D9, D10: LED; LED_0603_1608Metric_Pad1.05x0.95mm_HandSolder
D11: BLUE; LED_0603_1608Metric_Pad1.05x0.95mm_HandSolder
D12: GREEN; LED_0805_2012Metric_Pad1.15x1.40mm_HandSolder
D13: RED; LED_0805_2012Metric_Pad1.15x1.40mm_HandSolder
D14: BLUE; LED_0805_2012Metric_Pad1.15x1.40mm_HandSolder
DS1: TestPoint; TestPoint_Pad_D2.0mm
H1, H2: MountingHole_Pad; MountingHole_3.2mm_M3_ISO7380_Pad_TopBottom
H3, H4, H5: MountingHole; MountingHole_3.2mm_M3_ISO7380
J3, J4: Conn_01x19; PinSocket_1x19_P2.54mm_Vertical
J5: Micro_SD_Card; microSD_Yozaka_Interconnects_R2165
J6: Servo; PinHeader_1x03_P2.54mm_Vertical
J7, J17: I2C; PinSocket_1x04_P2.54mm_Vertical
J8: 5V Ext; PinHeader_1x02_P2.54mm_Horizontal
J13: DHT Sensor; PinSocket_1x04_P2.54mm_Vertical
J14: Pot; PinHeader_1x03_P2.54mm_Vertical
J15: Select A; PinHeader_1x03_P2.54mm_Vertical
J16: Select B; SolderJumper-3_P1.3mm_Bridged12_RoundedPad1.0x1.5mm_NumberL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
JP1: Jumper_2_Open; SolderJumper-2_P1.3mm_Open_RoundedPad1.0x1.5mm
JP2: Jumper_2_Bridged; SolderJumper-2_P1.3mm_Bridged_RoundedPad1.0x1.5mm
LOGO1: Logo_Open_Hardware_Small; KiCad-Logo2_5mm_SilkScreen
MR1: TestPoint; TestPoint_Pad_D2.0mm
Q1: IRLML6402; SOT-23
R5: 4k7; R_0805_2012Metric_Pad1.20x1.40mm_HandSolder
R6, R7, R16, R17, R19, R59: 10k; R_0805_2012Metric_Pad1.20x1.40mm_HandSolder
R8, R9, R10, R11, R12, R13, R14, R15, R21, R23, R26: 1k; R_0805_2012Metric_Pad1.20x1.40mm_HandSolder
R18, R22, R27: 560; R_0805_2012Metric_Pad1.20x1.40mm_HandSolder
R20: 1k2; R_0805_2012Metric_Pad1.20x1.40mm_HandSolder
R24: 3k9; R_0805_2012Metric_Pad1.20x1.40mm_HandSolder
R25: 1k8; R_0805_2012Metric_Pad1.20x1.40mm_HandSolder
R28: 330; R_0805_2012Metric_Pad1.20x1.40mm_HandSolder
R29: 10M; R_0805_2012Metric_Pad1.20x1.40mm_HandSolder
R30: LDR; R_LDR_5.1x4.3mm_P3.4mm_Vertical
R31: 150k; R_0805_2012Metric_Pad1.20x1.40mm_HandSolder
RV1: R_Potentiometer_Dual; Potentiometer_B103_Double_Slide
SO1: TestPoint; TestPoint_Pad_D2.0mm
ST1: TestPoint; TestPoint_Pad_D2.0mm
SW1, SW2, SW3, SW4, SW5, SW6: SW_Push; SW_PUSH-12mm
TP1, TP2: TestPoint; TestPoint_Pad_D2.0mm
U1: ESP32-DevKitC
U2: 74HC595; SOIC-16_3.9x9.9mm_P1.27mm
Y1: Crystal_GND3_Small; Crystal_AT310_D3.0mm_L10.0mm_Horizontal_1EP_style2

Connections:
+3V3: C1.1, C2.1, J3.1, J5.4 (VDD), J13.1, Q1.2 (S), R5.1, R6.1, R7.1, R19.1, R30.1, R59.1, RV1.3, SW1.2, SW2.2, SW3.2, SW4.2, SW5.2, U1.1 (3V3)
+5V: C4.1, C8.1, C13.1, J3.19, J6.2, J7.3, J8.2, J17.4, R17.2, U1.19 (5V), U2.16 (VCC)
/32K_XN: C7.2, J3.8, R29.2, U1.8 (32K_XN/GPIO33/ADC1_CH5), Y1.1
/32K_XP: C6.2, J3.7, R29.1, U1.7 (32K_XP/GPIO32/ADC1_CH4), Y1.2
/Analog_LDR: J3.5, R30.2, R31.1, U1.5 (VDET_1/GPIO34/ADC1_CH6)
/Analog_Pot: C3.1, J3.3, RV1.2, U1.3 (SENSOR_VP/GPIO36/ADC1_CH0)
/Analog_SW: J3.4, R23.1, R24.2, R25.2, R26.2, R27.2, R28.2, U1.4 (SENSOR_VN/GPIO39/ADC1_CH3)
/CD_uSD: J5.9 (CD), J16.3, R7.2
/CLK: J4.30, J5.5 (CLK), U1.30 (GPIO18)
/DHT_Data: J13.2, J15.1, R59.2
/Digital_SW: C5.2, J4.26, R19.2, SW6.1, U1.26 (ADC2_CH0/GPIO4)
/GPIO5: J4.29, J16.2, U1.29 (*GPIO5)
/GPIO12: J3.13, JP1.1 (A), U1.13 (*MTDI/GPIO12/ADC2_CH5)
/GPIO25: J3.9, J15.2, U1.9 (DAC_1/ADC2_CH8/GPIO25)
/MISO: J4.31, J5.7 (DAT0), U1.31 (GPIO19)
/MOSI: J4.37, J5.3 (CMD), R6.2, U1.37 (GPIO23)
/PWM: J6.3, J16.1
/SCL: J4.36, J7.2, J17.2, U1.36 (GPIO22)
/SDA: J4.33, J7.1, J17.1, U1.33 (GPIO21)
/SPI_CS_uSD: J3.15, JP2.1 (A), Q1.1 (G), U1.15 (MTCK/GPIO13/ADC2_CH4)
/SR DS: DS1.1, J3.10, U1.10 (DAC_2/ADC2_CH9/GPIO26), U2.14 (SER)
/SR MR: JP1.2 (B), MR1.1, R17.1, U2.10 (~SRCLR)
/SR SH_CP: J3.11, U1.11 (ADC2_CH7/GPIO27), U2.11 (SRCLK)
/SR ST_CP: J3.12, ST1.1, U1.12 (MTMS/GPIO14/ADC2_CH6), U2.12 (RCLK)
/SR ~OE: J15.3, R16.1, U2.13 (~OE)
/USER_LED_1: J4.24, R20.1, U1.24 (ADC2_CH2/*GPIO2)
/USER_LED_2: J4.25, R21.1, U1.25 (*GPIO0/BOOT/ADC2_CH1)
/USER_LED_3: J4.23, R22.1, U1.23 (*MTDO/GPIO15/ADC2_CH3)
GND: C1.2, C2.2, C3.2, C4.2, C5.1, C6.1, C7.1, C8.2, C12.2, C13.2, D3.1 (K), D4.1 (K), D5.1 (K), D6.1 (K), D7.1 (K), D8.1 (K), D9.1 (K), D10.1 (K), D11.1 (K), D12.1 (K), D13.1 (K), D14.1 (K), H1.1, H2.1, J3.14, J4.32, J4.38, J5.6 (VSS), J5.10 (SHIELD), J6.1, J7.4, J8.1, J13.4, J17.3, R16.2, R23.2, R31.2, RV1.1, RV1.7 (Shield), SW6.2, U1.14 (GND), U1.32 (GND), U1.38 (GND), U2.8 (GND), Y1.3
unnamed: C12.1, J3.2, U1.2 (CHIP_PU)
unnamed: D3.2 (A), R8.2
unnamed: D4.2 (A), R9.2
unnamed: D5.2 (A), R10.2
unnamed: D6.2 (A), R11.2
unnamed: D7.2 (A), R12.2
unnamed: D8.2 (A), R13.2
unnamed: D9.2 (A), R14.2
unnamed: D10.2 (A), R15.2
unnamed: D11.2 (A), R18.2
unnamed: D12.2 (A), R20.2
unnamed: D13.2 (A), R21.2
unnamed: D14.2 (A), R22.2
unnamed: J3.6, U1.6 (VDET_2/GPIO35/ADC1_CH7)
unnamed: J3.16, U1.16 (SD_DATA2/GPIO9)
unnamed: J3.17, U1.17 (SD_DATA3/GPIO10)
unnamed: J3.18, U1.18 (CMD)
unnamed: J4.20, U1.20 (SD_CLK/GPIO6)
unnamed: J4.21, U1.21 (SD_DATA0/GPIO7)
unnamed: J4.22, U1.22 (SD_DATA1/GPIO8)
unnamed: J4.27, U1.27 (GPIO16)
unnamed: J4.28, U1.28 (GPIO17)
unnamed: J4.34, U1.34 (U0RXD/GPIO3)
unnamed: J4.35, U1.35 (U0TXD/GPIO1)
unnamed: J5.1 (DAT2), TP1.1
unnamed: J5.2 (DAT3/CD), JP2.2 (B), R5.2
unnamed: J5.8 (DAT1), TP2.1
unnamed: J14.1, RV1.4
unnamed: J14.2, RV1.6
unnamed: J14.3, RV1.5
unnamed: Q1.3 (D), R18.1
unnamed: R8.1, U2.15 (QA)
unnamed: R9.1, U2.1 (QB)
unnamed: R10.1, U2.2 (QC)
unnamed: R11.1, U2.3 (QD)
unnamed: R12.1, U2.4 (QE)
unnamed: R13.1, U2.5 (QF)
unnamed: R14.1, U2.6 (QG)
unnamed: R15.1, U2.7 (QH)
unnamed: R24.1, SW1.1
unnamed: R25.1, SW2.1
unnamed: R26.1, SW3.1
unnamed: R27.1, SW4.1
unnamed: R28.1, SW5.1
unnamed: SO1.1, U2.9 (QH')

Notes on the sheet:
Shift Register "SER" Serial data input = GPIO26 "SRCLK Serial Clock" = GPIO27 "RCLK" Latch = GPIO14
Input only
Support de carte micro SD
OLED
GPIO0 LED Red
0,67 V
GPIO39 A3
RX0
LED Green
=== Strapping Pins === The ESP32 chip has the following strapping pins: GPIO 0 (must be LOW to enter boot mode) GPIO 2 (must be floating or LOW during boot) GPIO 4 GPIO 5 (must be HIGH during boot) GPIO 12 (must be LOW during boot) GPIO 15 (must be HIGH during boot)
TX0
https://cdn.shopify.com/s/files/1/0609/6011/2892/files/doc-esp32-pinout-reference-wroom-devkit.png https://www.upesy.fr/blogs/tutorials/esp32-pinout-reference-gpio-pins-ultimate-guide
Servo Moteur
External Pull-Up Resistor
Modèle du module 38 broches "ESP32-WROOM-32D"
3x LEDs utilisateur
Correspondance pour l'ADC1 : | ADC1 | GPIO | | ------ | ----- | | ADC1_CH0 | GPIO 36 | | ADC1_CH1 | GPIO 37 | | ADC1_CH2 | GPIO 38 | | ADC1_CH3 | GPIO 39 | | ADC1_CH4 | GPIO 32 | | ADC1_CH5 | GPIO 33 | | ADC1_CH6 | GPIO 34 | | ADC1_CH7 | GPIO 35 |
1,18 V
LED Blue
TX2
GPIO14 for latchPin "RCLK"
LED Red
RX2
10u
2,48 V
GPIO4
GPIO15 LED Blue
TODO : - Ajouter sur sérigraphie Bottom © 2023, Arnauld Biganzoli, GPL 3... - Ajout de symboles pour les éléments de sérigraphie (ceux-ci disparaissent si ils ne sont pas associés à un symbole) - Changer LED par RED
Commutateur digital 1 voie
GPIO26 for serialDataPin "SER"
GPIO2 LED Green
sd card socket
GPIO27 for clockPin "SRCLK (Serial Clock)"
Commutateur analogique 5 voies
MPU6050
GPIO34 A6
DNP
Registre à décalage 8 bits
Photorésistance (LDR)
GPIO36 A0

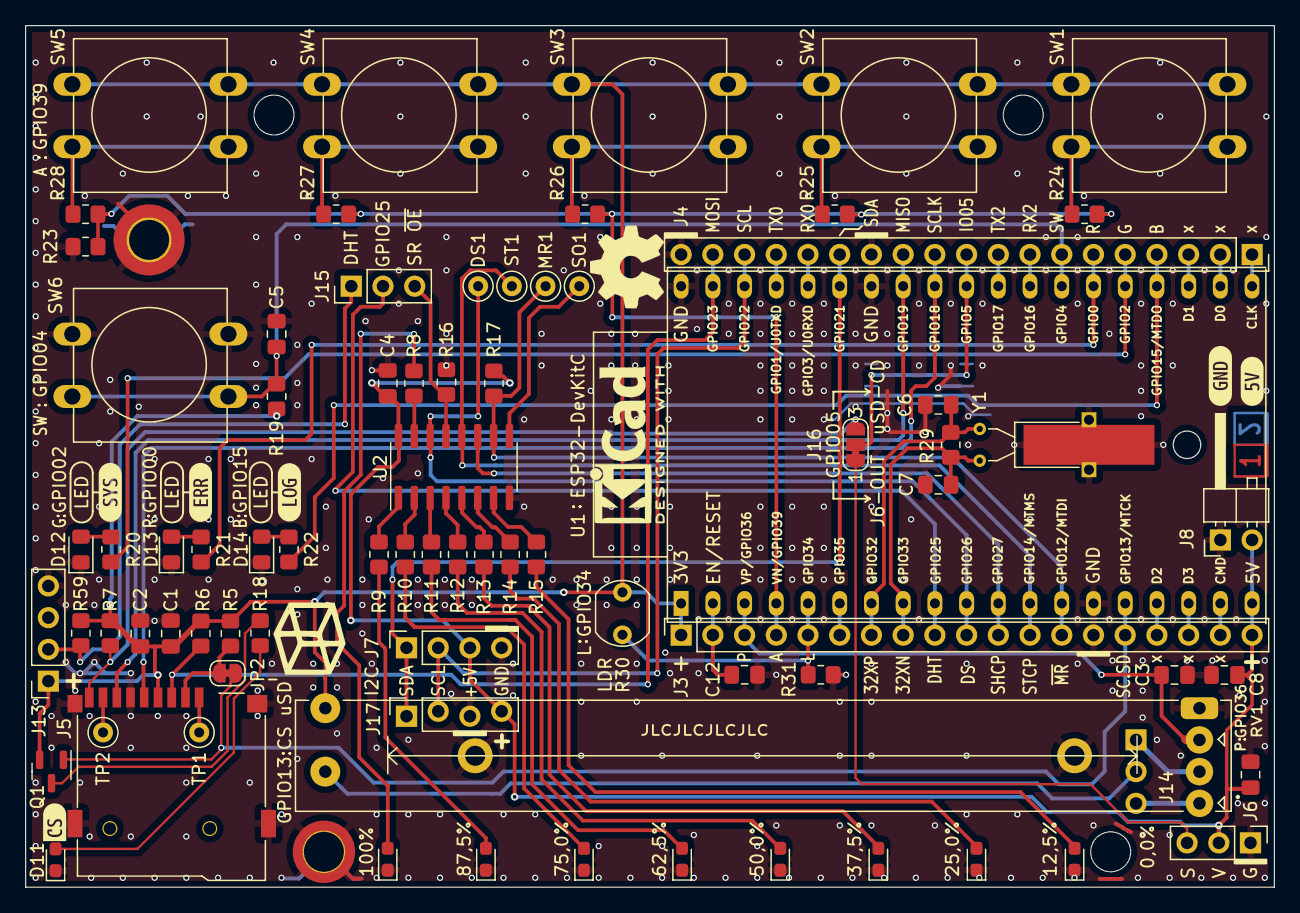
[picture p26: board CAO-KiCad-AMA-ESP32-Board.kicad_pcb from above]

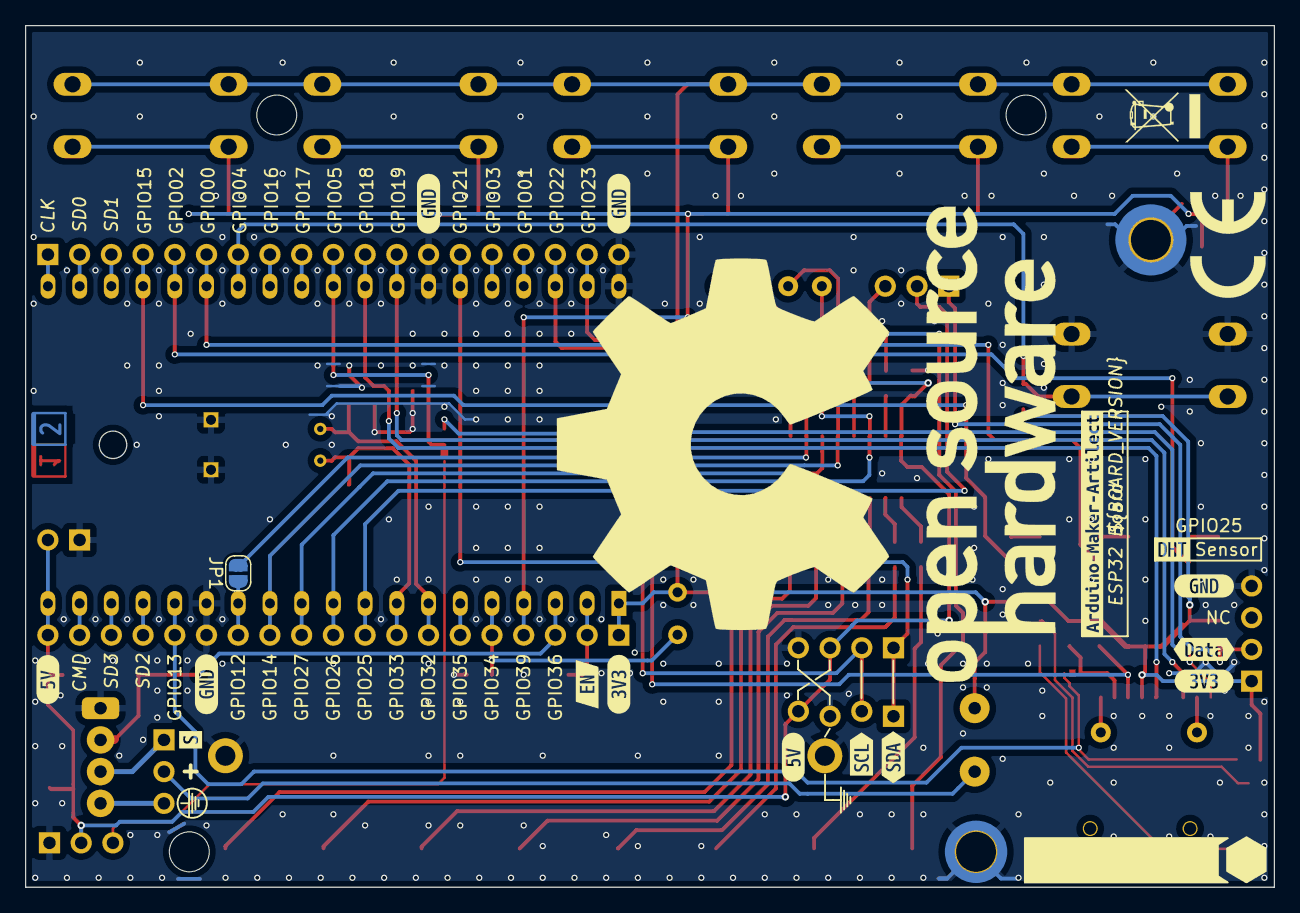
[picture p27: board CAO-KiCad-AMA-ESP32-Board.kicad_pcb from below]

Board: 2 copper layers, 100.0 x 69.0 mm, 108 parts (16 on the bottom side), 74 nets.

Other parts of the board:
Layer-x2: VAL**; Layer-indicator-two-side
kibuzzard-1, kibuzzard-1#2, kibuzzard-1#3: G***; kibuzzard-6367F8E9
kibuzzard-63A1FAC6: G***; kibuzzard-63A1FAC6
kibuzzard-63A1FB19: G***; kibuzzard-63A1FB19
kibuzzard-63A33E4B, kibuzzard-63A33E4B#2: G***; kibuzzard-63A33E4B
kibuzzard-63A33F4C: G***; kibuzzard-63A33F4C
kibuzzard-63A45C8C: G***; kibuzzard-63A45C8C
kibuzzard-63A457E7: G***; kibuzzard-63A457E7
kibuzzard-63A470E3: G***; kibuzzard-63A470E3
kibuzzard-63A34430: G***; kibuzzard-63A34430
kibuzzard-63A45813: G***; kibuzzard-63A45813
kibuzzard-63A48047: G***; kibuzzard-63A48047
kibuzzard-63ADDA63: G***; kibuzzard-63ADDA63
kibuzzard-639F4895: G***; kibuzzard-639F4895
kibuzzard-6367FF54, kibuzzard-6367FF54#2, kibuzzard-6367FF54#3, kibuzzard-6367FF54#4, kibuzzard-6367FF54#5: G***; kibuzzard-6367FF54

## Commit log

2021-11-26 Creation du projet KiCad
    [CAO-KiCad.kicad_pcb, CAO-KiCad.kicad_sch]
2021-11-26 Mise a jour de la doc
2021-11-29 Debut de la creation du module ESP32
    [CAO-KiCad.kicad_pcb, CAO-KiCad.kicad_sch]
2021-11-29 Arrangement des broches du symbole de l'ESP32
    [CAO-KiCad.kicad_pcb, CAO-KiCad.kicad_sch]
2021-12-01 MAJ empreinte
    [CAO-KiCad.kicad_pcb, CAO-KiCad.kicad_sch]
2022-12-30 Remplacement du forme factor Uno par la carte A-M-A avec ESP32-WROOM-32D 38 broches
    [CAO-KiCad-AMA-ESP32-Board.kicad_pcb, CAO-KiCad-AMA-ESP32-Board.kicad_sch, CAO-KiCad.kicad_pcb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]
2022-12-30 Ajout du schématique et de la BOM
    [CAO-KiCad-AMA-ESP32-Board.kicad_pcb, CAO-KiCad-AMA-ESP32-Board.kicad_sch]
2022-12-31 Mise à jour de la BOM
2023-01-08 Correction majeur sur le GPIO12, doit-être à l'état bas lors du démarrage de l'ESP32
    [CAO-KiCad-AMA-ESP32-Board.kicad_pcb, CAO-KiCad-AMA-ESP32-Board.kicad_sch]
2023-03-01 MAJ valeurs R pour LEDs
    [CAO-KiCad-AMA-ESP32-Board.kicad_pcb, CAO-KiCad-AMA-ESP32-Board.kicad_sch]
